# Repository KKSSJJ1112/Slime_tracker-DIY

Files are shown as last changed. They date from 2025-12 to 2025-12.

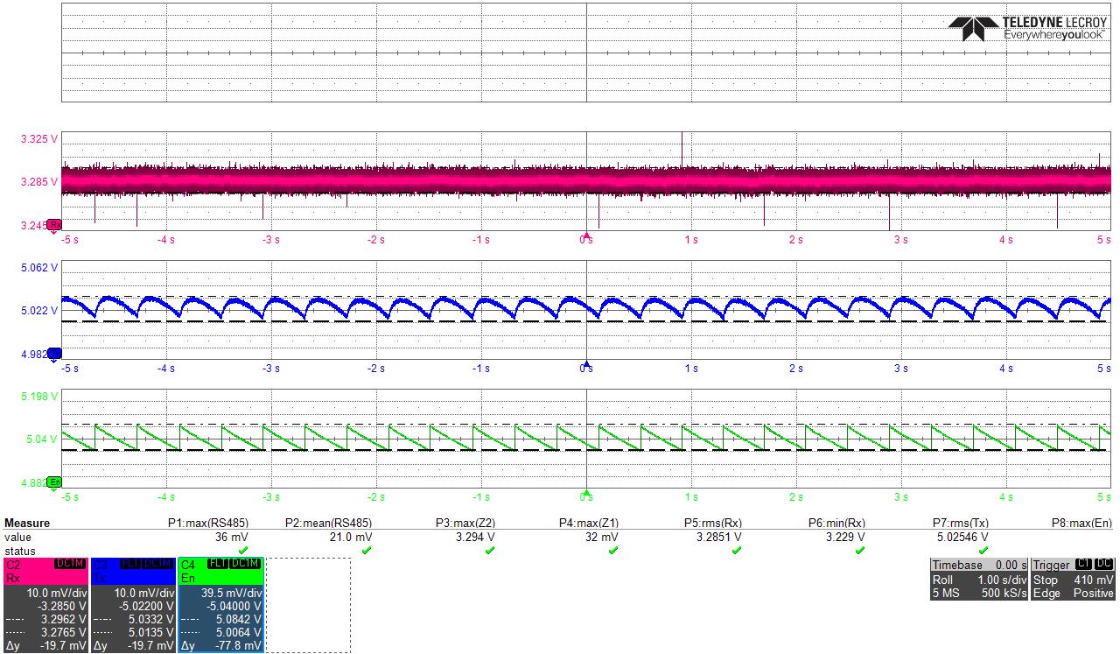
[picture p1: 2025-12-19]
1--00222.jpg

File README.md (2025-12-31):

asd

# UNCZ_Slime_tracker

[English](#english) | [한국어](#한국어)

---

## English

### Overview
Custom SlimeVR tracker.

### Specifications
| Item | Description |
|---|---|
| MCU | ESP32-C3 Super Mini |
| IMU | SlimeVR Mumo Breakout Module V1 (ICM-45686 + QMC6309) |
| Battery | 1100mAh Li-Po |
| PCB Size | ~80mm x 30mm |

### Features
- **Optimized Power Circuit**: Minimized ripple and noise compared
- **Compact Form Factor**: Streamlined 2-layer PCB design
- **Production Ready**: Includes JLCPCB manufacturing files

### Repository Structure
```
├── 3D/                    # 3D model files (case, mount, etc.)
├── Datasheets/            # Component datasheets
├── KiCad/                 # KiCad project files
│   ├── *.kicad_pcb
│   ├── *.kicad_sch
│   └── *.kicad_pro
└── Production/            # Manufacturing files
    ├── BOM.csv            # Bill of Materials (JLCPCB format)
    ├── PartList.csv       # Component list
    └── Positions.csv      # Pick and place file
```

### Manufacturing
Production files are optimized for JLCPCB:
1. Upload Gerber files from `Production/` folder
2. Use provided BOM and position files for SMT assembly

### Power Circuit Comparison
<!-- Add your oscilloscope comparison images here -->


77mv -> 20mv

From bottom to top: immediately after boost converter, after LC filter, and before final IMU power supply.

### License
- Hardware (PCB, Schematics, 3D files): [MIT License](LICENSE)
- Documentation: [CC BY-SA 4.0](https://creativecommons.org/licenses/by-sa/4.0/)

### Revision History
- **Rev02** (Current): Power circuit, Charging circuit changed
- **Rev01**: Initial design

---

## 한국어

### 개요
커스텀 SlimeVR 트래커입니다.

### 사양
| 항목 | 내용 |
|---|---|
| MCU | ESP32-C3 Super Mini |
| IMU | SlimeVR Mumo Breakout Module V1 (ICM-45686 + QMC6309) |
| 배터리 | 1100mAh Li-Po |
| PCB 크기 | 약 80mm x 30mm |

### 특징
- **전원부 최적화**: 리플 및 노이즈 최소화
- **컴팩트 설계**: 2레이어 PCB 기반 간결한 설계
- **양산 대응**: JLCPCB 제조 파일 포함

### 저장소 구조
```
├── 3D/                    # 3D 모델 파일 (케이스, 마운트 등)
├── Datasheets/            # 부품 데이터시트
├── KiCad/                 # KiCad 프로젝트 파일
│   ├── *.kicad_pcb
│   ├── *.kicad_sch
│   └── *.kicad_pro
└── Production/            # 제조용 파일
    ├── BOM.csv            # 부품 목록 (JLCPCB 형식)
    ├── PartList.csv       # 파트 리스트
    └── Positions.csv      # 부품 배치 파일
```

### 제조 방법
JLCPCB 기준 제조 파일 제공:
1. `Production/` 폴더의 거버 파일 업로드
2. 제공된 BOM 및 위치 파일로 SMT 조립 주문

#### 전원부 비교
<!-- 오실로스코프 비교 이미지 추가 예정 -->



77mv -> 20mv 

맨 아래부터 승압 직후, LC필터 이후, 최종 imu공급 직전

### 라이선스
- Hardware (PCB, Schematics, 3D files): [MIT License](LICENSE)
- Documentation: [CC BY-SA 4.0](https://creativecommons.org/licenses/by-sa/4.0/)

### 변경 이력
- **Rev02** (현재): 전원부, 충전부 수정
- **Rev01**: 최초 설계

---

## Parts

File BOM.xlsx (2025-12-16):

Value | Reference | Qty | Footprint | JLCPCB Part #
1uF | C1 | 1 | Capacitor_SMD:C_0805_2012Metric | C28323
10uF | C2,C12,C13 | 3 | Capacitor_SMD:C_1206_3216Metric | C13585
22uF | C3 | 1 | Capacitor_SMD:C_1206_3216Metric | C12891
100nF | C4 | 1 | Capacitor_SMD:C_1206_3216Metric | C24497
2.2uF | C5 | 1 | Capacitor_SMD:C_1206_3216Metric | C50254
10uF | C6 | 1 | Capacitor_SMD:C_0805_2012Metric | C15850
100nF | C7 | 1 | Capacitor_SMD:C_0805_2012Metric | C49678
100uF | C8 | 1 | CASE-V-7343-19 | C219004
4.7uF | C10 | 1 | Capacitor_SMD:C_1206_3216Metric | C29823
1uF | C11 | 1 | Capacitor_SMD:C_1206_3216Metric | C1848
red | D1 | 1 | LED_SMD:LED_0805_2012Metric | C84256
green | D2 | 1 | LED_SMD:LED_0805_2012Metric | C2297
D | D3 | 1 | Diode_SMD:D_SOD-123 | C7420328
FerriteBead | FB1 | 1 | Resistor_SMD:R_0805_2012Metric | C1017
USB_C_Receptacle_PowerOnly_6P | J3 | 1 | Connector_USB:USB_C_Receptacle_GCT_USB4135-GF-A_6P_TopMnt_Horizontal | C5438410
6.8uH | L1 | 1 | slime:FXL0420 | C177241
2.2uH | L2 | 1 | slime:FXL0420 | C167206
2MΩ | R1,R5 | 2 | Resistor_SMD:R_0603_1608Metric | C22976
33Ω | R2,R3,R6 | 3 | Resistor_SMD:R_0603_1608Metric | C23140
330kΩ | R4 | 1 | Resistor_SMD:R_0603_1608Metric | C23137
220kΩ | R8 | 1 | Resistor_SMD:R_0603_1608Metric | C22961
1MΩ | R9 | 1 | Resistor_SMD:R_0603_1608Metric | C22935
4.7kΩ | R10 | 1 | Resistor_SMD:R_0603_1608Metric | C23162
2kΩ | R11 | 1 | Resistor_SMD:R_0603_1608Metric | C22975
10kΩ | R18 | 2 | Resistor_SMD:R_0603_1608Metric | C25804
1kΩ | R13,R14 | 2 | Resistor_SMD:R_0603_1608Metric | C21190
1Ω | R15,R19 | 2 | Resistor_SMD:R_1206_3216Metric | C17928
5.1kΩ | R16,R17 | 2 | Resistor_SMD:R_0603_1608Metric | C23186
TP4056 | U1 | 1 | slime:TP4056_ESOP8 | C725790
TPS7A0333PDBVR | U3 | 1 | Package_TO_SOT_SMD:SOT-23-5 | C3749797
TPS61090 | U5 | 1 | Package_DFN_QFN:QFN-16-1EP_4x4mm_P0.65mm_EP2.7x2.7mm_PullBack_ThermalVias | C206167

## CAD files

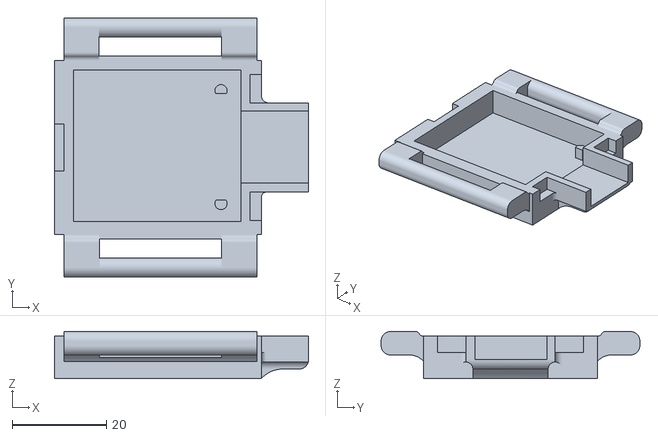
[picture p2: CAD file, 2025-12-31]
3D/sub main.stl
54.0 x 55.0 x 10.0

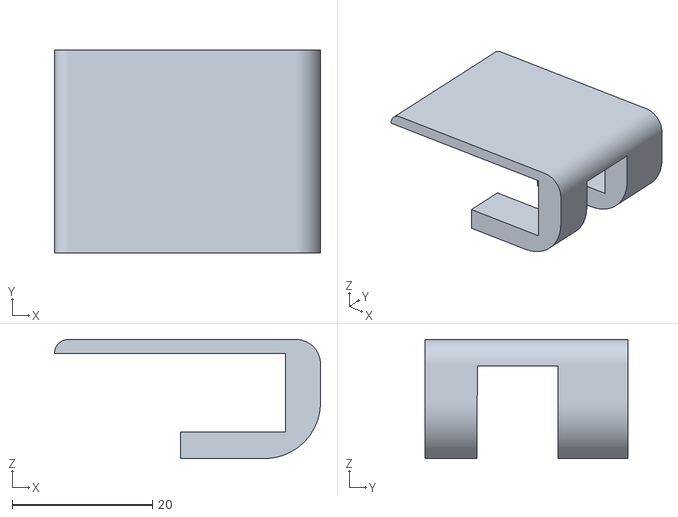
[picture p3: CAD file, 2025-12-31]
3D/chest guide2.stl
38.0 x 29.0 x 17.0

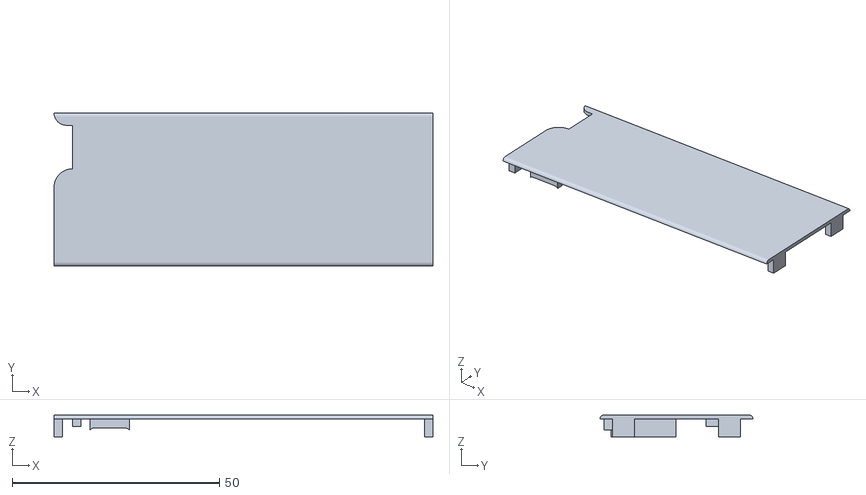
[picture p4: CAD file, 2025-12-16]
top final.stl
91.5 x 37.0 x 5.30

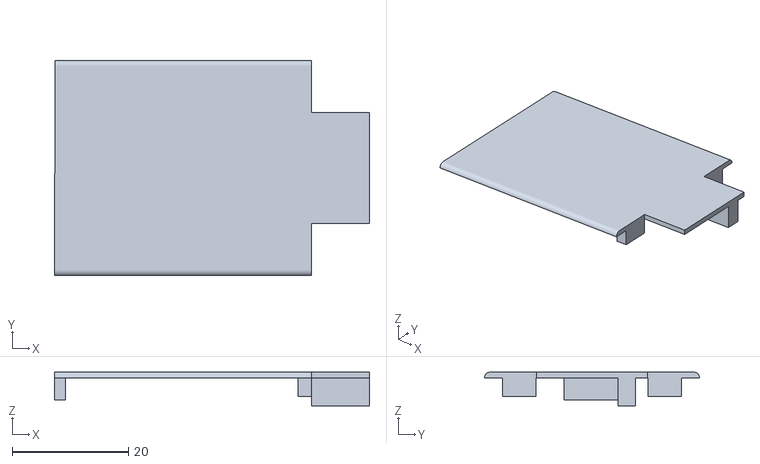
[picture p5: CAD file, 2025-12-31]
3D/sub top.stl
54.1 x 37.0 x 5.80

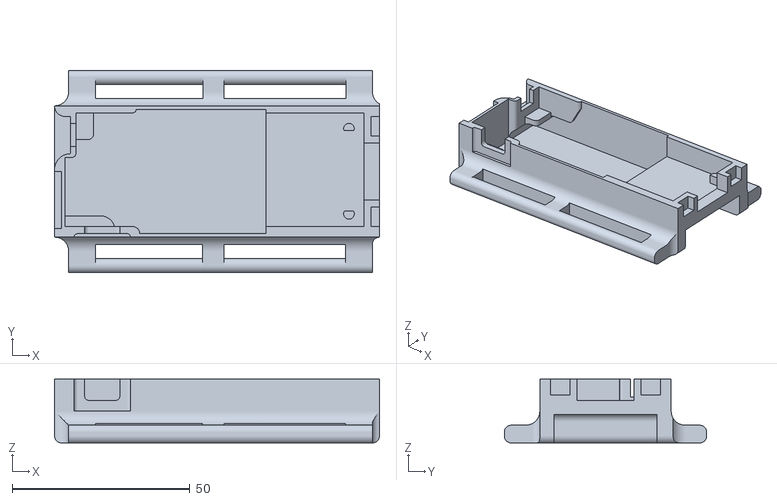
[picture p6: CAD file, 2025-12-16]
3D/base final.stl
91.5 x 57.0 x 18.0

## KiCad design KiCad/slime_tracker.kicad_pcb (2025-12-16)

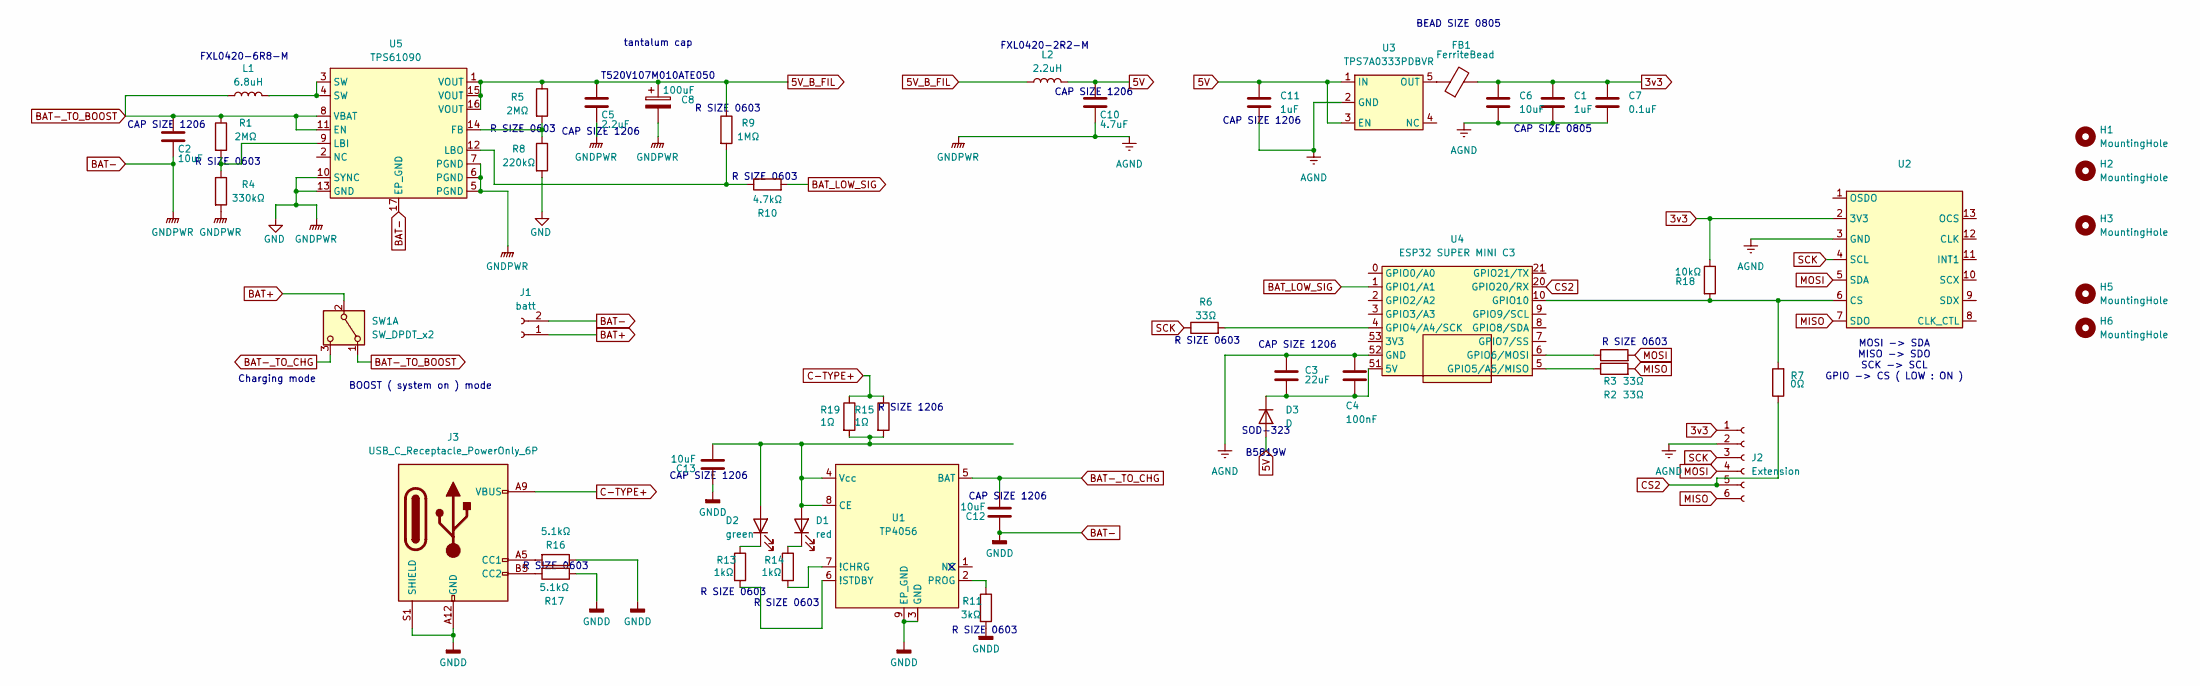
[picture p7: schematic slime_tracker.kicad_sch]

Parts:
C1: 1uF; C_0805_2012Metric
C2, C12, C13: 10uF; C_1206_3216Metric
C3: 22uF; C_1206_3216Metric
C4: 100nF; C_1206_3216Metric
C5: 2.2uF; C_1206_3216Metric
C6: 10uF; C_0805_2012Metric
C7: 0.1uF; C_0805_2012Metric
C8: 100uF; CP_EIA-7343-20_Kemet-V
C10: 4.7uF; C_1206_3216Metric
C11: 1uF; C_1206_3216Metric
D1: red; LED_0805_2012Metric
D2: green; LED_0805_2012Metric
D3: D; D_SOD-123
FB1: FerriteBead; R_0805_2012Metric
H1, H2: MountingHole; MountingHole_3.2mm_M3
H3, H5, H6: MountingHole; ToolingHole_1.152mm
J1: batt; JST_PH_S2B-PH-K_1x02_P2.00mm_Horizontal
J2: Extension; JST_PH_S6B-PH-K_1x06_P2.00mm_Horizontal
J3: USB_C_Receptacle_PowerOnly_6P; USB_C_Receptacle_GCT_USB4135-GF-A_6P_TopMnt_Horizontal
L1: 6.8uH; FXL0420
L2: 2.2uH; FXL0420
R1, R5: 2MΩ; R_0603_1608Metric
R2, R3, R6: 33Ω; R_0603_1608Metric
R4: 330kΩ; R_0603_1608Metric
R7: 0Ω; R_0603_1608Metric
R8: 220kΩ; R_0603_1608Metric
R9: 1MΩ; R_0603_1608Metric
R10: 4.7kΩ; R_0603_1608Metric
R11: 3kΩ; R_0603_1608Metric
R13, R14: 1kΩ; R_0603_1608Metric
R15, R19: 1Ω; R_1206_3216Metric
R16, R17: 5.1kΩ; R_0603_1608Metric
R18: 10kΩ; R_0603_1608Metric
SW1: SW_DPDT_x2; SW_Slide_SPDT_Angled_CK_OS102011MA1Q
U1: TP4056; TP4056_ESOP8
U2: Slime_IMU_mumo
U3: TPS7A0333PDBVR; SOT-23-5
U4: ESP32 SUPER MINI C3; esp32
U5: TPS61090; QFN-16-1EP_4x4mm_P0.65mm_EP2.7x2.7mm_PullBack_ThermalVias

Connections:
3v3: C1.1, C6.1, C7.1, FB1.2, J2.1, R18.1, U2.2 (3V3)
5V: C10.2, C11.1, D3.2 (A), L2.2, U3.1 (IN), U3.3 (EN)
5V_B_FIL: C5.2, C8.1, L2.1, R5.1, R9.1, U5.1 (VOUT), U5.15 (VOUT), U5.16 (VOUT)
BAT+: J1.1, SW1.2 (B)
BAT-: C1.2, C2.1, C3.2, C4.2, C5.1, C6.2, C7.2, C8.2, C10.1, C11.2, C12.2, C13.2, J1.2, J2.2, J3.A12 (GND), J3.B12 (GND), J3.S1 (SHIELD), R4.2, R8.2, R11.2, R16.1, R17.1, U1.3 (GND), U1.9 (EP_GND), U2.3 (GND), U3.2 (GND), U4.52 (GND), U5.5 (PGND), U5.6 (PGND), U5.7 (PGND), U5.10 (SYNC), U5.13 (GND), U5.17 (EP_GND)
BAT-_TO_BOOST: C2.2, L1.1, R1.1, SW1.1 (A), U5.8 (VBAT), U5.11 (EN)
BAT-_TO_CHG: C12.1, SW1.3 (C), U1.5 (BAT)
BAT_LOW_SIG: R10.2, U4.1 (GPIO1/A1)
C-TYPE+: J3.A9 (VBUS), J3.B9 (VBUS), R15.1, R19.1
CS2: J2.5, R7.1, U4.20 (GPIO20/RX)
MISO: J2.6, R2.2, U2.7 (SDO)
MOSI: J2.4, R3.2, U2.5 (SDA)
unnamed: C13.1, D1.2 (A), D2.2 (A), R15.2, R19.2, U1.4 (Vcc), U1.8 (CE)
unnamed: D1.1 (K), R14.1
unnamed: D2.1 (K), R13.1
unnamed: C3.1, C4.1, D3.1 (K), U4.51 (5V)
unnamed: J3.A5 (CC1), R16.2
unnamed: J3.B5 (CC2), R17.2
unnamed: L1.2, U5.3 (SW), U5.4 (SW)
unnamed: R14.2, U1.7 (!CHRG)
unnamed: R13.2, U1.6 (!STDBY)
unnamed: R11.1, U1.2 (PROG)
unnamed: R7.2, R18.2, U2.6 (CS), U4.10 (GPIO10)
unnamed: FB1.1, U3.5 (OUT)
unnamed: R6.2, U4.4 (GPIO4/A4/SCK)
unnamed: R2.1, U4.5 (GPIO5/A5/MISO)
unnamed: R3.1, U4.6 (GPIO6/MOSI)
unnamed: R5.2, R8.1, U5.14 (FB)
unnamed: R1.2, R4.1, U5.9 (LBI)
unnamed: R9.2, R10.1, U5.12 (LBO)
SCK: J2.3, R6.1, U2.4 (SCL)

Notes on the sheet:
R SIZE 0603
CAP SIZE 1206
R SIZE 1206
BOOST ( system on ) mode
FXL0420-2R2-M
CAP SIZE 0805
tantalum cap T520V107M010ATE050
FXL0420-6R8-M
SOD-323 B5819W
Charging mode
BEAD SIZE 0805
MOSI -> SDA MISO -> SDO SCK -> SCL GPIO -> CS ( LOW : ON )

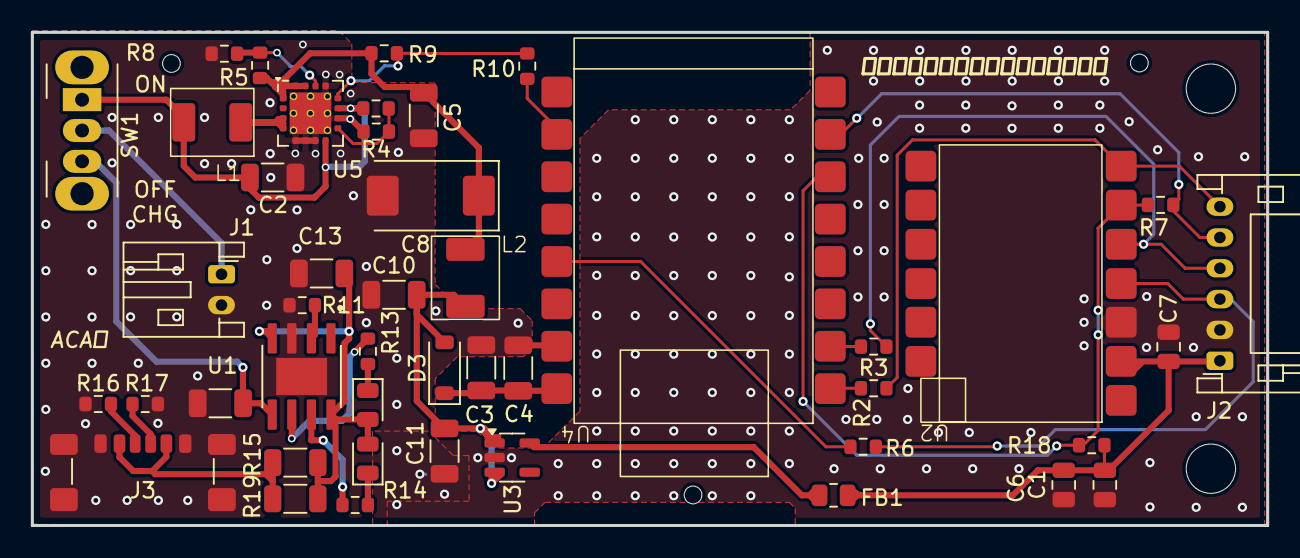
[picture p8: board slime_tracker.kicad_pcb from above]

Board: 2 copper layers, 80.2 x 32.0 mm, 50 parts (0 on the bottom side), 31 nets.

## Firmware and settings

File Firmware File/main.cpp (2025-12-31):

/*
    SlimeVR Code is placed under the MIT license
    Copyright (c) 2021 Eiren Rain & SlimeVR contributors
*/

#include <i2cscan.h>
#include "GlobalVars.h"
#include "Wire.h"
#include "batterymonitor.h"
#include "credentials.h"
#include "debugging/TimeTaken.h"
#include "globals.h"
#include "logging/Logger.h"
#include "ota.h"
#include "serial/serialcommands.h"
#include "status/TPSCounter.h"

Timer<> globalTimer;
SlimeVR::Logging::Logger logger("SlimeVR");
SlimeVR::Sensors::SensorManager sensorManager;
SlimeVR::LEDManager ledManager;
SlimeVR::Status::StatusManager statusManager;
SlimeVR::Configuration::Configuration configuration;
SlimeVR::Network::Manager networkManager;
SlimeVR::Network::Connection networkConnection;
SlimeVR::WiFiNetwork wifiNetwork;
SlimeVR::WifiProvisioning wifiProvisioning;

#if DEBUG_MEASURE_SENSOR_TIME_TAKEN
SlimeVR::Debugging::TimeTakenMeasurer sensorMeasurer{"Sensors"};
#endif

int sensorToCalibrate = -1;
bool blinking = false;
unsigned long blinkStart = 0;
unsigned long loopTime = 0;
unsigned long lastStatePrint = 0;
bool secondImuActive = false;
BatteryMonitor battery;
TPSCounter tpsCounter;

void setup() {
    // 시리얼 통신 시작 (USB CDC On Boot 설정이 중요)
    Serial.begin(serialBaudRate);
    globalTimer = timer_create_default();

    Serial.println();
    Serial.println();
    Serial.println();

    logger.info("SlimeVR v" FIRMWARE_VERSION " starting up...");

    char vendorBuffer[512];
    size_t writtenLength;

    if (strlen(VENDOR_URL) == 0) {
        sprintf(vendorBuffer, "Vendor: %s, product: %s%n", VENDOR_NAME, PRODUCT_NAME, &writtenLength);
    } else {
        sprintf(vendorBuffer, "Vendor: %s (%s), product: %s%n", VENDOR_NAME, VENDOR_URL, PRODUCT_NAME, &writtenLength);
    }

    if (strlen(UPDATE_ADDRESS) > 0 && strlen(UPDATE_NAME) > 0) {
        sprintf(vendorBuffer + writtenLength, ", firmware update url: %s, name: %s", UPDATE_ADDRESS, UPDATE_NAME);
    }
    logger.info("%s", vendorBuffer);

    statusManager.setStatus(SlimeVR::Status::LOADING, true);

    // [최우선] SDO 핀을 먼저 설정 (센서 주소 충돌 방지)
#ifdef PIN_IMU_SDO
    pinMode(PIN_IMU_SDO, OUTPUT);
    digitalWrite(PIN_IMU_SDO, HIGH);
    delay(200); // 충분한 안정화 시간 (USB 미연결 시에도 안정적)
    logger.info("GPIO%d (SDO) set to HIGH for dual sensor setup", PIN_IMU_SDO);
#endif

    ledManager.setup();
    configuration.setup();

    SerialCommands::setUp();

    auto clearResult = I2CSCAN::clearBus(PIN_IMU_SDA, PIN_IMU_SCL);
    if (clearResult != 0) {
        logger.warn("Can't clear I2C bus, error %d", clearResult);
    }

#ifdef ESP32
    Wire.end();
#endif
    Wire.begin(static_cast<int>(PIN_IMU_SDA), static_cast<int>(PIN_IMU_SCL));
#ifdef ESP32
    Wire.setTimeOut(150);
#endif
    Wire.setClock(I2C_SPEED);

    // IMU 부팅을 위한 대기
    delay(500);

    // [핵심] sensorManager.setup() 내부에서 SPI 초기화가 진행됩니다.
    sensorManager.setup();

    // WiFi credentials 강제 설정 (빌드 캐시 문제 우회)
    #ifndef WIFI_CREDS_SSID
    #define WIFI_CREDS_SSID "your-ssid"
    #define WIFI_CREDS_PASSWD "your-password"
    #endif
    logger.info("WiFi credentials: SSID='%s', Pass length=%d", WIFI_CREDS_SSID, strlen(WIFI_CREDS_PASSWD));

    networkManager.setup();
    OTA::otaSetup(otaPassword);
    battery.Setup();

    statusManager.setStatus(SlimeVR::Status::LOADING, false);

    sensorManager.postSetup();

    loopTime = micros();
    tpsCounter.reset();
}

void loop() {
    tpsCounter.update();
    globalTimer.tick();
    SerialCommands::update();
    OTA::otaUpdate();
    networkManager.update();

#if DEBUG_MEASURE_SENSOR_TIME_TAKEN
    sensorMeasurer.before();
#endif
    sensorManager.update();
#if DEBUG_MEASURE_SENSOR_TIME_TAKEN
    sensorMeasurer.after();
#endif

    battery.Loop();
    ledManager.update();
    
    // [수정] I2C 스캔 업데이트 비활성화
    // I2CSCAN::update();

#ifdef TARGET_LOOPTIME_MICROS
    long elapsed = (micros() - loopTime);
    if (elapsed < TARGET_LOOPTIME_MICROS) {
        long sleepus = TARGET_LOOPTIME_MICROS - elapsed - 100;
        long sleepms = sleepus / 1000;
        if (sleepms > 0) {
            delay(sleepms);
            sleepus -= sleepms * 1000;
        }
        if (sleepus > 100) {
            delayMicroseconds(sleepus);
        }
    }
    loopTime = micros();
#endif

#if defined(PRINT_STATE_EVERY_MS) && PRINT_STATE_EVERY_MS > 0
    unsigned long now = millis();
    if (lastStatePrint + PRINT_STATE_EVERY_MS < now) {
        lastStatePrint = now;
        SerialCommands::printState();
    }
#endif
}

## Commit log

2025-11-13 imu 풋프린트 필요
2025-11-18 FROM HOME
    [slime_tracker_bom.xlsx]
2025-12-16 3D file
    3D file
    [base final.stl, top final.stl]
2025-12-16 Rename base final.stl to 3D/base final.stl
    [base final.stl]
2025-12-16 for JLCPCB
    [BOM.xlsx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]
2025-12-16 Revise README for power circuit and licensing details
    Updated the README with power circuit comparison details, license information, and revision history.
2025-12-31 subTracker added
    [chest guide2.stl, sub main.stl, sub top.stl]
2026-01-16 IC2, SPI explain added
    and N.C R added
    [slime_tracker.kicad_sch]
